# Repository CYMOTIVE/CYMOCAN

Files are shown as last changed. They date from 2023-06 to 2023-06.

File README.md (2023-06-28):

# CYMOCAN USB-CAN Interface #

CYMOCAN is a low cost USB to CAN-FD (Controller Area Network - Flexible Data rate) interface.

Using the [CandleLight firmware](https://github.com/candle-usb/candleLight_fw) CYMOCAN can work with Windows(WCID USB) and Linux(SocketCAN over gs_usb).

## What is in this repository?

* Hardware files for the CYMOCAN board and [Debug edge](https://debug-edge.io/) breakout board

## Hardware
## CYMOCAN_G0
CYMOCAN_G0 has:
* 2 CAN-FD interfaces 
* USB
* SWD + UART (Over [Debug edge](https://debug-edge.io/))

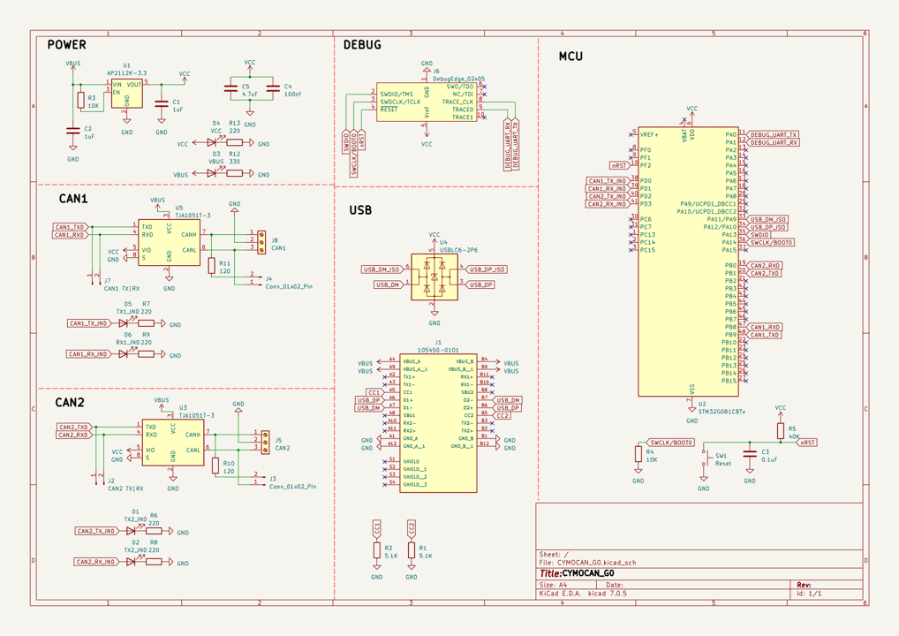
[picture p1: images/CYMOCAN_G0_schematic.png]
CYMOCAN_G0 Schematic


CYMOCAN_G0 BOM
|Reference|Description|Quantity|
|:---|:---:|:---:|
| C1, C2 | 0603 1uF Capacitor | 2
| C3| 0603 0.1uF Capacitor | 1
| C4 | 0603 100nf Capacitor | 1
| C5 | 0603 4.7uF Capacitor | 1
| D1, D2, D3, D4, D5, D6 | 0603 LED | 6
| J1 | Molex 105450-0101 USB-C socket | 1
| J2, J3, J4, J7 | 01x02 Pin Header | 4
| J5, J8 | 3 Pin TerminalBlock Bornier 5.08mm | 2
| R1, R2 | 0603 5.1K Resistor | 2
| R3, R4 | 0603 10K Resistor | 2
| R5 | 0603 40K Resistor | 1
| R6, R7, R8, R9, R13 | 0603 220 Resistor | 5
| R10, R11 | 0603 120 Resistor | 2
| R12 | 0603 330 Resistor | 1
| SW1 | Push switch 6mm THT | 1
| U1 | AP2112K-3.3 LDO regulator| 1
| U2 | STM32G0B1CBT6 Microcontroller | 1
| U3, U5 | TJA1051T-3 CAN transceiver | 2
| U4 | USBLC6-2P6 USB ESD protection diodes| 1

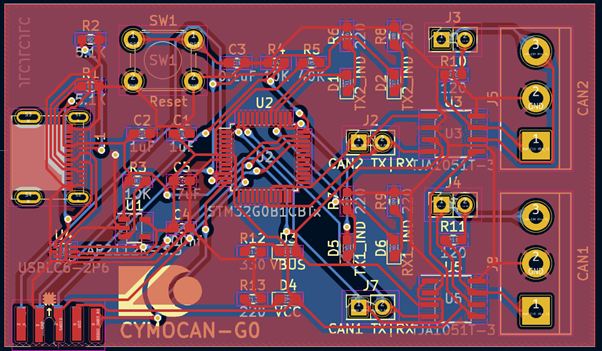
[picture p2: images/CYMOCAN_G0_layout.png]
CYMOCAN_G0


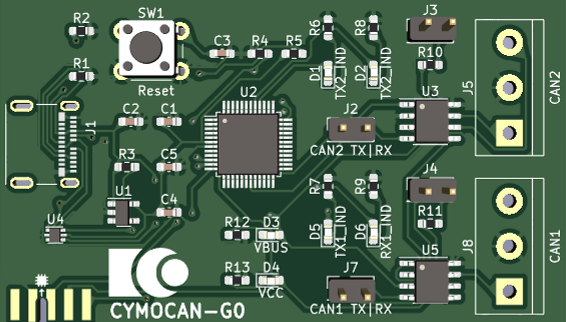
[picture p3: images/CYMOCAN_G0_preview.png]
CYMOCAN_G0


## Debug edge breakout
You Do not need this in order to flash and use the CYMOCAN board.
This breakout is only necessary if you wish to debug the board during development. 

## Getting started with CYMOCAN ##
### Flashing the Board ###
After assembling the device follow the flashing instructions in the [CandleLight firmware](https://github.com/candle-usb/candleLight_fw) Repo.

For now use the PR https://github.com/candle-usb/candleLight_fw/pull/139 and the nucleo_g0b1re target.

### Linux ###
You will need to compile a kernel version 5.18 or above for GS_USB CAN-FD support.
The flags you must enable are:
* CAN
* CAN_GS_USB

After compiling and installing the Kernel the CYMOCAN will appear as a standard SocketCAN device.

To setup the device for classic CAN use the following commands
```
sudo ip link set can0 qlen 1000
sudo ip link set can0 up type can bitrate 500000
```
Subsitute can0 for the channel you are using.
Now you can use the device with any SocketCAN compatible software.

### Windows ###
TODO

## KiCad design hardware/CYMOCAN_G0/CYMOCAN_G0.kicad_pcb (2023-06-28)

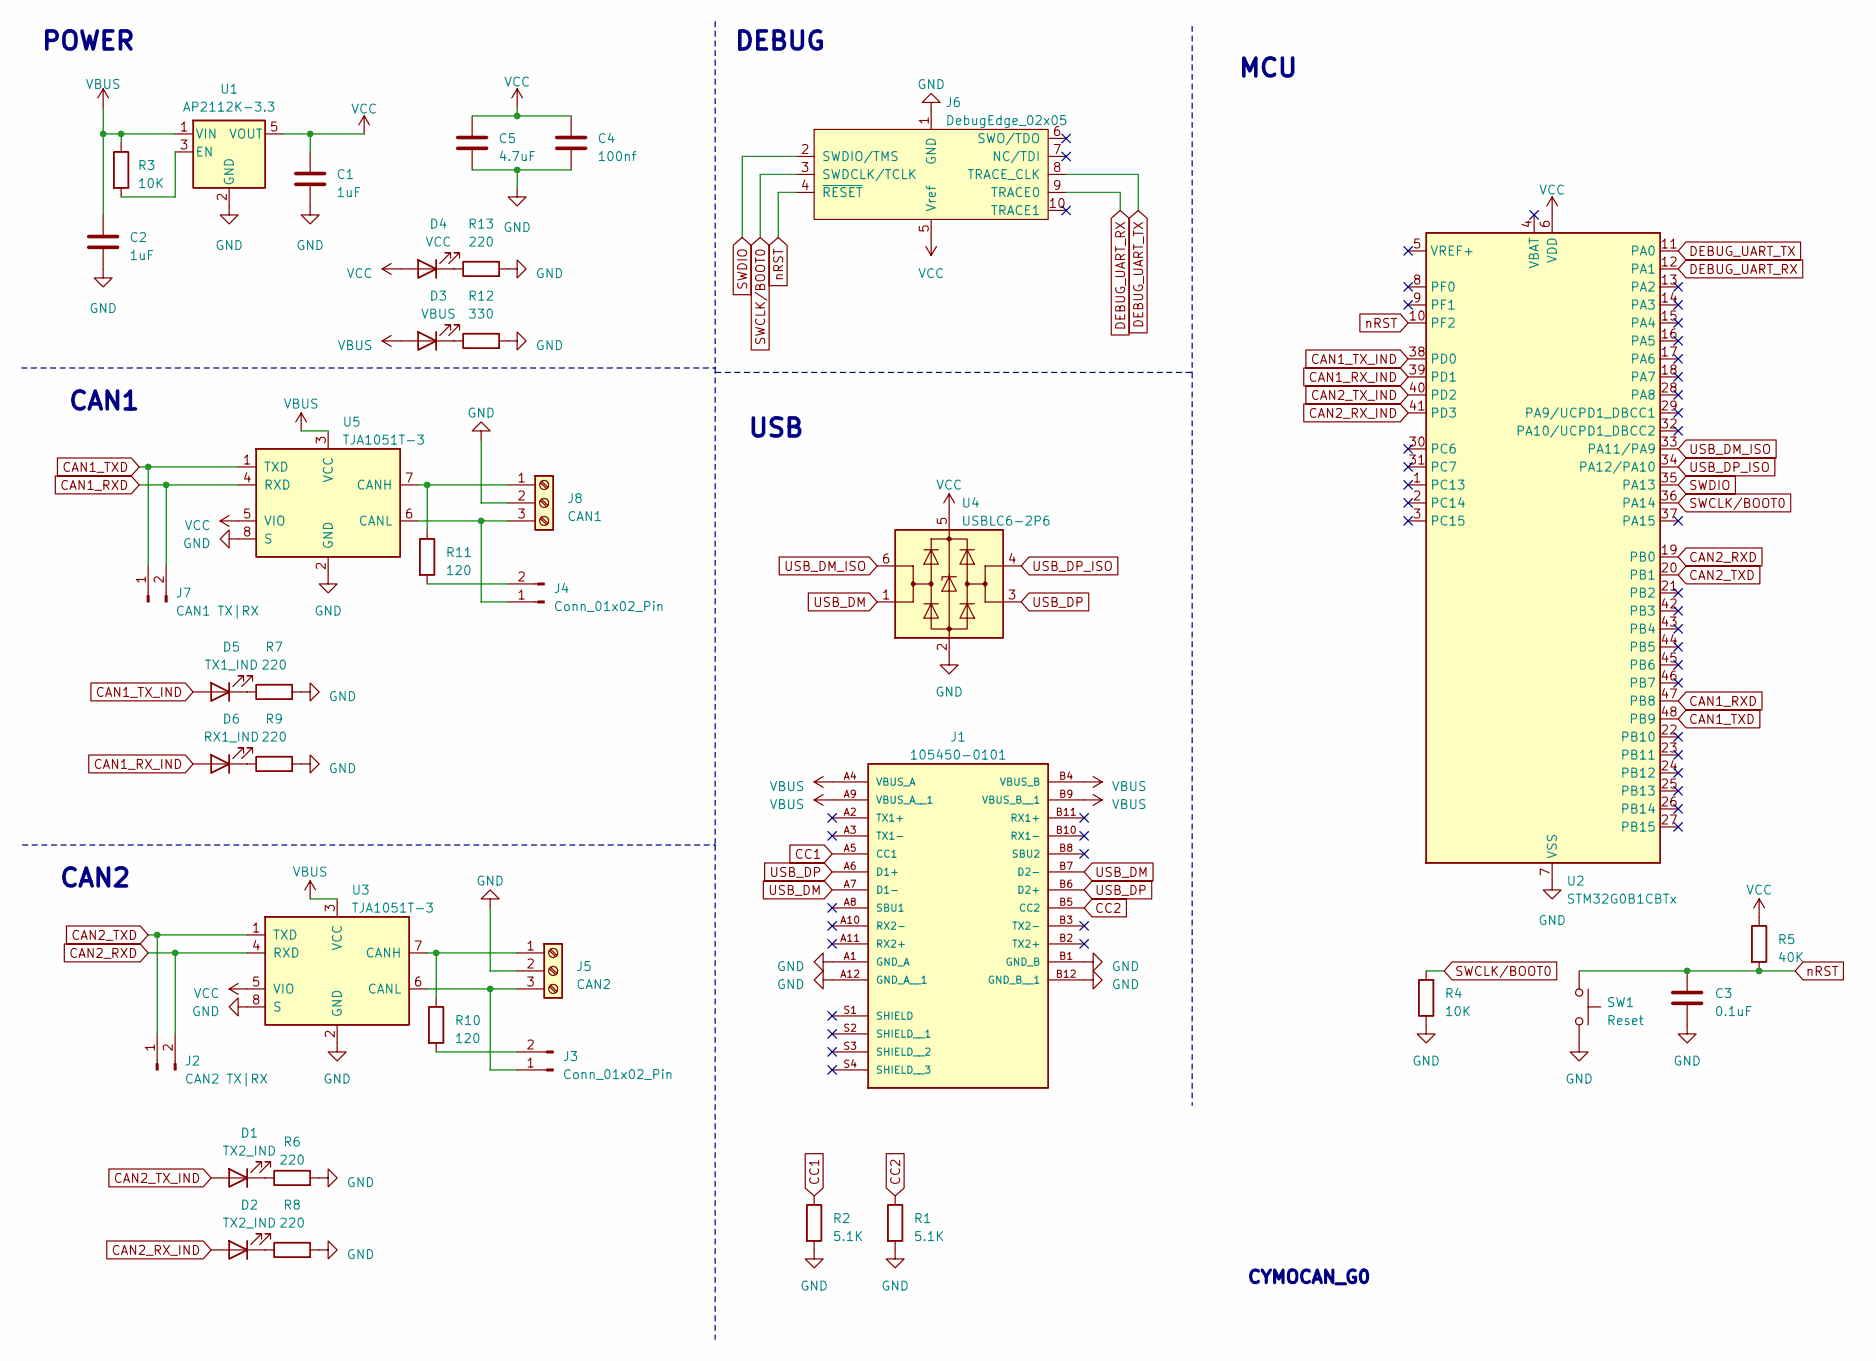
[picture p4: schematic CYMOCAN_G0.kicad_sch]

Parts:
C1, C2: 1uF; C_0603_1608Metric_Pad1.08x0.95mm_HandSolder
C3: 0.1uF; C_0603_1608Metric_Pad1.08x0.95mm_HandSolder
C4: 100nf; C_0603_1608Metric_Pad1.08x0.95mm_HandSolder
C5: 4.7uF; C_0603_1608Metric_Pad1.08x0.95mm_HandSolder
D1, D2: TX2_IND; LED_0603_1608Metric_Pad1.05x0.95mm_HandSolder
D3: VBUS; LED_0603_1608Metric_Pad1.05x0.95mm_HandSolder
D4: VCC; LED_0603_1608Metric_Pad1.05x0.95mm_HandSolder
D5: TX1_IND; LED_0603_1608Metric_Pad1.05x0.95mm_HandSolder
D6: RX1_IND; LED_0603_1608Metric_Pad1.05x0.95mm_HandSolder
J1: 105450-0101; MOLEX_105450-0101; PARTREV A7
J2: CAN2 TX|RX; PinHeader_2x01_P2.54mm_Vertical
J3, J4: Conn_01x02_Pin; PinHeader_2x01_P2.54mm_Vertical
J5: CAN2; TerminalBlock_bornier-3_P5.08mm
J6: DebugEdge_02x05; DebugEdge_2x05_Target
J7: CAN1 TX|RX; PinHeader_2x01_P2.54mm_Vertical
J8: CAN1; TerminalBlock_bornier-3_P5.08mm
R1, R2: 5.1K; R_0603_1608Metric_Pad0.98x0.95mm_HandSolder
R3, R4: 10K; R_0603_1608Metric_Pad0.98x0.95mm_HandSolder
R5: 40K; R_0603_1608Metric_Pad0.98x0.95mm_HandSolder
R6, R7, R8, R9, R13: 220; R_0603_1608Metric_Pad0.98x0.95mm_HandSolder
R10, R11: 120; R_0603_1608Metric_Pad0.98x0.95mm_HandSolder
R12: 330; R_0603_1608Metric_Pad0.98x0.95mm_HandSolder
SW1: Reset; SW_PUSH_6mm
U1: AP2112K-3.3; SOT-23-5
U2: STM32G0B1CBTx; LQFP-48_7x7mm_P0.5mm
U3, U5: TJA1051T-3; SOIC-8_3.9x4.9mm_P1.27mm
U4: USBLC6-2P6; SOT-666

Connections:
CAN1_RXD: J7.2, U2.47 (PB8), U5.4 (RXD)
CAN1_RX_IND: D6.2 (A), U2.39 (PD1)
CAN1_TXD: J7.1, U2.48 (PB9), U5.1 (TXD)
CAN1_TX_IND: D5.2 (A), U2.38 (PD0)
CAN2_RXD: J2.2, U2.19 (PB0), U3.4 (RXD)
CAN2_RX_IND: D2.2 (A), U2.41 (PD3)
CAN2_TXD: J2.1, U2.20 (PB1), U3.1 (TXD)
CAN2_TX_IND: D1.2 (A), U2.40 (PD2)
CC1: J1.A5 (CC1), R2.1
CC2: J1.B5 (CC2), R1.1
DEBUG_UART_RX: J6.9 (TRACE0), U2.12 (PA1)
DEBUG_UART_TX: J6.8 (TRACE_CLK), U2.11 (PA0)
GND: C1.2, C2.2, C3.2, C4.2, C5.2, J1.A1 (GND_A), J1.A12 (GND_A__1), J1.B1 (GND_B), J1.B12 (GND_B__1), J5.2, J6.1 (GND), J8.2, R1.2, R2.2, R4.1, R6.2, R7.2, R8.2, R9.2, R12.2, R13.2, SW1.2, U1.2 (GND), U2.7 (VSS), U3.2 (GND), U3.8 (S), U4.2 (GND), U5.2 (GND), U5.8 (S)
unnamed: D1.1 (K), R6.1
unnamed: D2.1 (K), R8.1
unnamed: D3.1 (K), R12.1
unnamed: D4.1 (K), R13.1
unnamed: D5.1 (K), R7.1
unnamed: D6.1 (K), R9.1
unnamed: J3.1, J5.3, U3.6 (CANL)
unnamed: J3.2, R10.2
unnamed: J4.1, J8.3, U5.6 (CANL)
unnamed: J4.2, R11.2
unnamed: J5.1, R10.1, U3.7 (CANH)
unnamed: J8.1, R11.1, U5.7 (CANH)
unnamed: R3.2, U1.3 (EN)
SWCLK/BOOT0: J6.3 (SWDCLK/TCLK), R4.2, U2.36 (PA14)
SWDIO: J6.2 (SWDIO/TMS), U2.35 (PA13)
USB_DM: J1.A7 (D1-), J1.B7 (D2-), U4.1 (I/O1)
USB_DM_ISO: U2.33 (PA11/PA9), U4.6 (I/O1)
USB_DP: J1.A6 (D1+), J1.B6 (D2+), U4.3 (I/O2)
USB_DP_ISO: U2.34 (PA12/PA10), U4.4 (I/O2)
VBUS: C2.1, D3.2 (A), J1.A4 (VBUS_A), J1.A9 (VBUS_A__1), J1.B4 (VBUS_B), J1.B9 (VBUS_B__1), R3.1, U1.1 (VIN), U3.3 (VCC), U5.3 (VCC)
VCC: C1.1, C4.1, C5.1, D4.2 (A), J6.5 (Vref), R5.1, U1.5 (VOUT), U2.6 (VDD), U3.5 (VIO), U4.5 (VBUS), U5.5 (VIO)
nRST: C3.1, J6.4 (~RESET), R5.2, SW1.1, U2.10 (PF2)

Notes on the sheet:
CAN1
USB
MCU
DEBUG
POWER
CYMOCAN_G0
CAN2

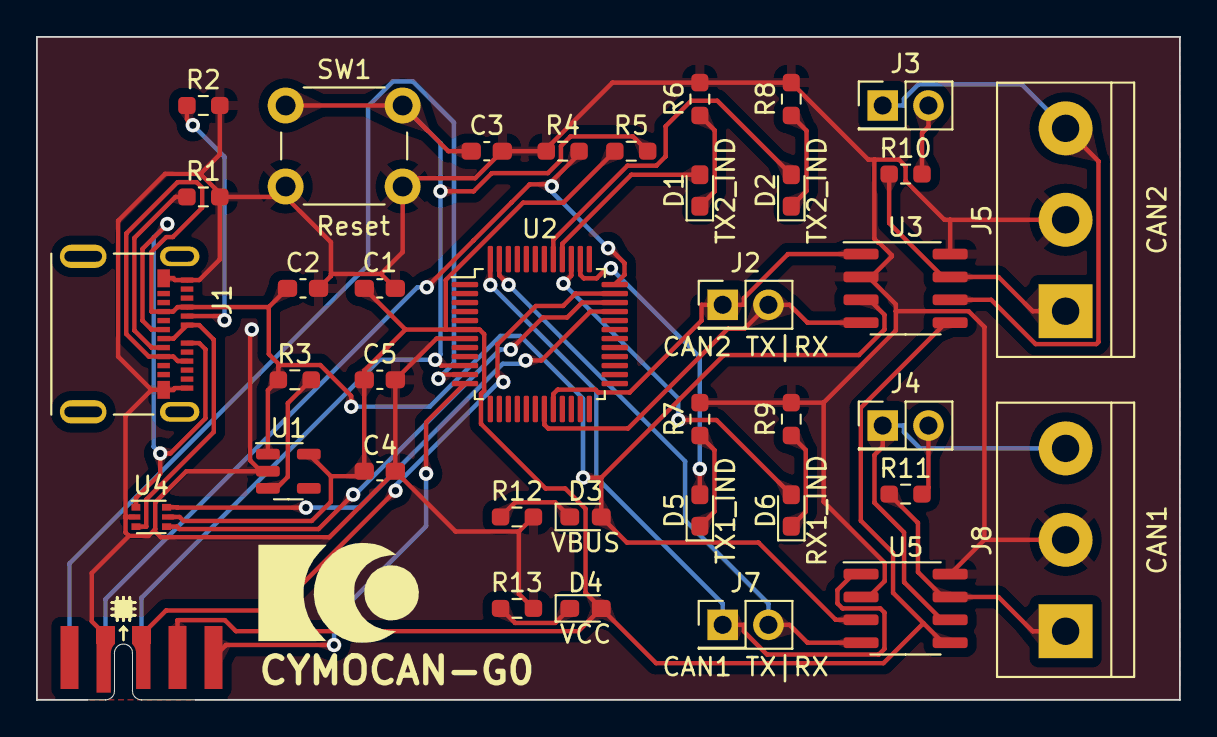
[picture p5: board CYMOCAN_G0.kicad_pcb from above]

Board: 2 copper layers, 63.5 x 36.8 mm, 38 parts (0 on the bottom side), 35 nets.

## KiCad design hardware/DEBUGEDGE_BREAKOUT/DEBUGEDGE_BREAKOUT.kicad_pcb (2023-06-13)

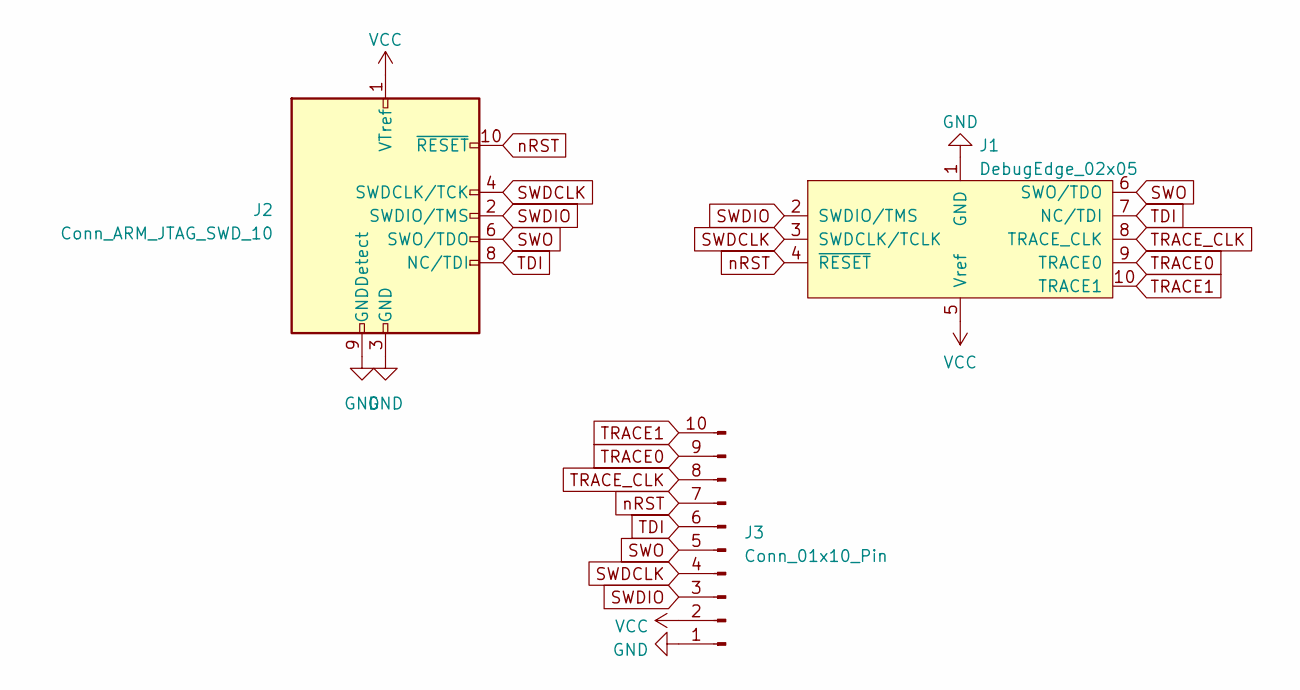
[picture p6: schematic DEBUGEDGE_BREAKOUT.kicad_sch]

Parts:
J1: DebugEdge_02x05; DebugEdge_2x05_Host
J2: Conn_ARM_JTAG_SWD_10; PinHeader_2x05_P1.27mm_Vertical_SMD
J3: Conn_01x10_Pin; PinHeader_1x10_P2.54mm_Vertical

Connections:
GND: J1.1 (GND), J2.3 (GND), J2.5 (GND), J2.9 (GNDDetect), J3.1
SWDCLK: J1.3 (SWDCLK/TCLK), J2.4 (SWDCLK/TCK), J3.4
SWDIO: J1.2 (SWDIO/TMS), J2.2 (SWDIO/TMS), J3.3
SWO: J1.6 (SWO/TDO), J2.6 (SWO/TDO), J3.5
TDI: J1.7 (NC/TDI), J2.8 (NC/TDI), J3.6
TRACE0: J1.9 (TRACE0), J3.9
TRACE1: J1.10 (TRACE1), J3.10
TRACE_CLK: J1.8 (TRACE_CLK), J3.8
VCC: J1.5 (Vref), J2.1 (VTref), J3.2
nRST: J1.4 (~RESET), J2.10 (~RESET), J3.7

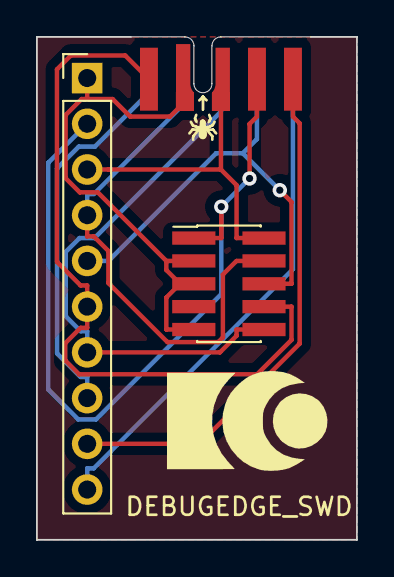
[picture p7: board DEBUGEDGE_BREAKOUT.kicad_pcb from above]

Board: 2 copper layers, 17.8 x 27.9 mm, 3 parts (0 on the bottom side), 10 nets.

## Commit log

2023-04-18 Add Kicad files to .gitignore
2023-04-18 Initial work on schema
    [CYMOCAN_G0.kicad_pcb, CYMOCAN_G0.kicad_sch]
2023-04-18 Update .gitignore Kicad files
2023-06-02 Updated terminal block and footprints
    [CYMOCAN_G0.kicad_sch]
2023-06-04 Layout complete
    [CYMOCAN_G0.kicad_pcb, CYMOCAN_G0.kicad_sch]
2023-06-12 Fix DRC issues and Restructure
    [CYMOCAN_G0.kicad_pcb, CYMOCAN_G0.kicad_sch]
2023-06-12 Fix DRC issues
    [CYMOCAN_G0.kicad_pcb]
2023-06-12 Add DebugEdge Breakout board
    [DEBUGEDGE_BREAKOUT.kicad_pcb, DEBUGEDGE_BREAKOUT.kicad_sch]
2023-06-13 Adjust JLC placeholder
    [CYMOCAN_G0.kicad_pcb]
2023-06-13 Fix footprints and jlc placeholder in DebugEdge Breakout
    [DEBUGEDGE_BREAKOUT.kicad_pcb, DEBUGEDGE_BREAKOUT.kicad_sch]
2023-06-28 Fix Led Resistor values
    [CYMOCAN_G0.kicad_pcb, CYMOCAN_G0.kicad_sch]
2023-06-28 Fix typo in D2 LED label
    [CYMOCAN_G0.kicad_sch]
